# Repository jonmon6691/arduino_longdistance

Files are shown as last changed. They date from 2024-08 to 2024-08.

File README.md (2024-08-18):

# arduino_LongDistance
An improvement to [arduino_RustysCalling](https://github.com/jonmon6691/arduino_rustyscalling/) that increases range, responsiveness, battery life, reduces complexity, and even folds your laundry!

## Todo
* Clean up phone wiring, can I get a new handset??
* Add wiring for dial
* Power button
  * Toggle button with LED
  * LED can be powered directly with 3.3V output, brightness is good at 2k series R, current is only .5ma

## Remote
This module is simply a button and a LoRa transmitter.

While the button is pressed, the remote transmitts packets as fast as it can. Otherwise it's idle, not sending anything.

Note: To maximize the packet rate (and therefore increase the responsiveness), the modems use the `.setModemConfig(RH_RF95::Bw500Cr45Sf128)` setting to optimize speed at the cost of distance. In practice this results in a packet every 8ms. The range appears to be more than sufficient, even when the rx is closed inside the phone.

### Feather Option
https://www.adafruit.com/product/3178

Battery life for a SAMD Radiofruit with a 350mAh little lipo pack is about 1 week. Would be nice if this was replaceable...
<br />
__Note:__ that's with 1mA while asleep (not using RFM sleep), 120mA while transmitting

### BSN3 Option
https://github.com/EasySensors/ButtonSizeNode3

Programs just like an Arduino Pro Mini, directly with an FTDI cable. Using sleep state for the Mega and for radio its down to 4 microamps. The two CR2032's (255mAh @ 6.5V) should last 7 years!!! I need to double check my ammeter tbh

## Phone
The LoRa receiver also orchestrates the phones other functions

### Ringer
Every time the phone receives a LoRa packet, it will run the ringer for the next 20 milliseconds. Since the packets come every 8ms, this means the ringer will stay on without interruption while the remote button held down, and will ring for about 20ms after its released. Which isn't noticeable.

To turn on the ringer, the microcontroller drives the gate of an N-channel FET with a 3.3k pulldown resistor. That FET provides a path to ground for a ringer module which converts the DC of a 9V battery into 70V 20Hz AC to power the ringer directly.

* Experiments on making the ringer louder
  * 2x A23 in parallel,(172mA) Not significantly louder, but less voltage drop during ringing (4v drop vs 2v drop) and will probably last a lot longer
  * 12v wall wart, (210mA) not significantly louder, no voltage drop at all while ringing.
  * 1x 9V, (160mA) not significantly quieter, but could in theory last a lot longer, like 20x
  * 2x A23 in series (24v) doesn't work, but thankfully, doesn't break the ringer either
  * 2x 9V in series (18.5v) doesn't work, but thankfully, doesn't break the ringer either
  * __Conclusion__: Using single 9V battery for convinience and longevity
* Power consumption
  * ESP + Lora listening = 81mA! 68mA of that is from the ESP by itself. Surely there's a way to lower this, maybe Wifi or BT is on??
  * Audio FX board: 29mA idle

### Playing audio
When the handset is lifted off the cradle, the phone will play a random audio file through the speaker.

The audio is generated by an Adafruit SFX board which is controlled using UART from the LoRa receiver module.

When the handset is placed back on the cradle, the audio will stop.

When the dial is turned and the handset is off the cradle, the current audio will be interrupted and the phone will play a giggling noise. When it's released, it will start a new audio.

The ground of the audio board is driven with another FET like the ringer module so that the power consumption can be cut by the main controller.

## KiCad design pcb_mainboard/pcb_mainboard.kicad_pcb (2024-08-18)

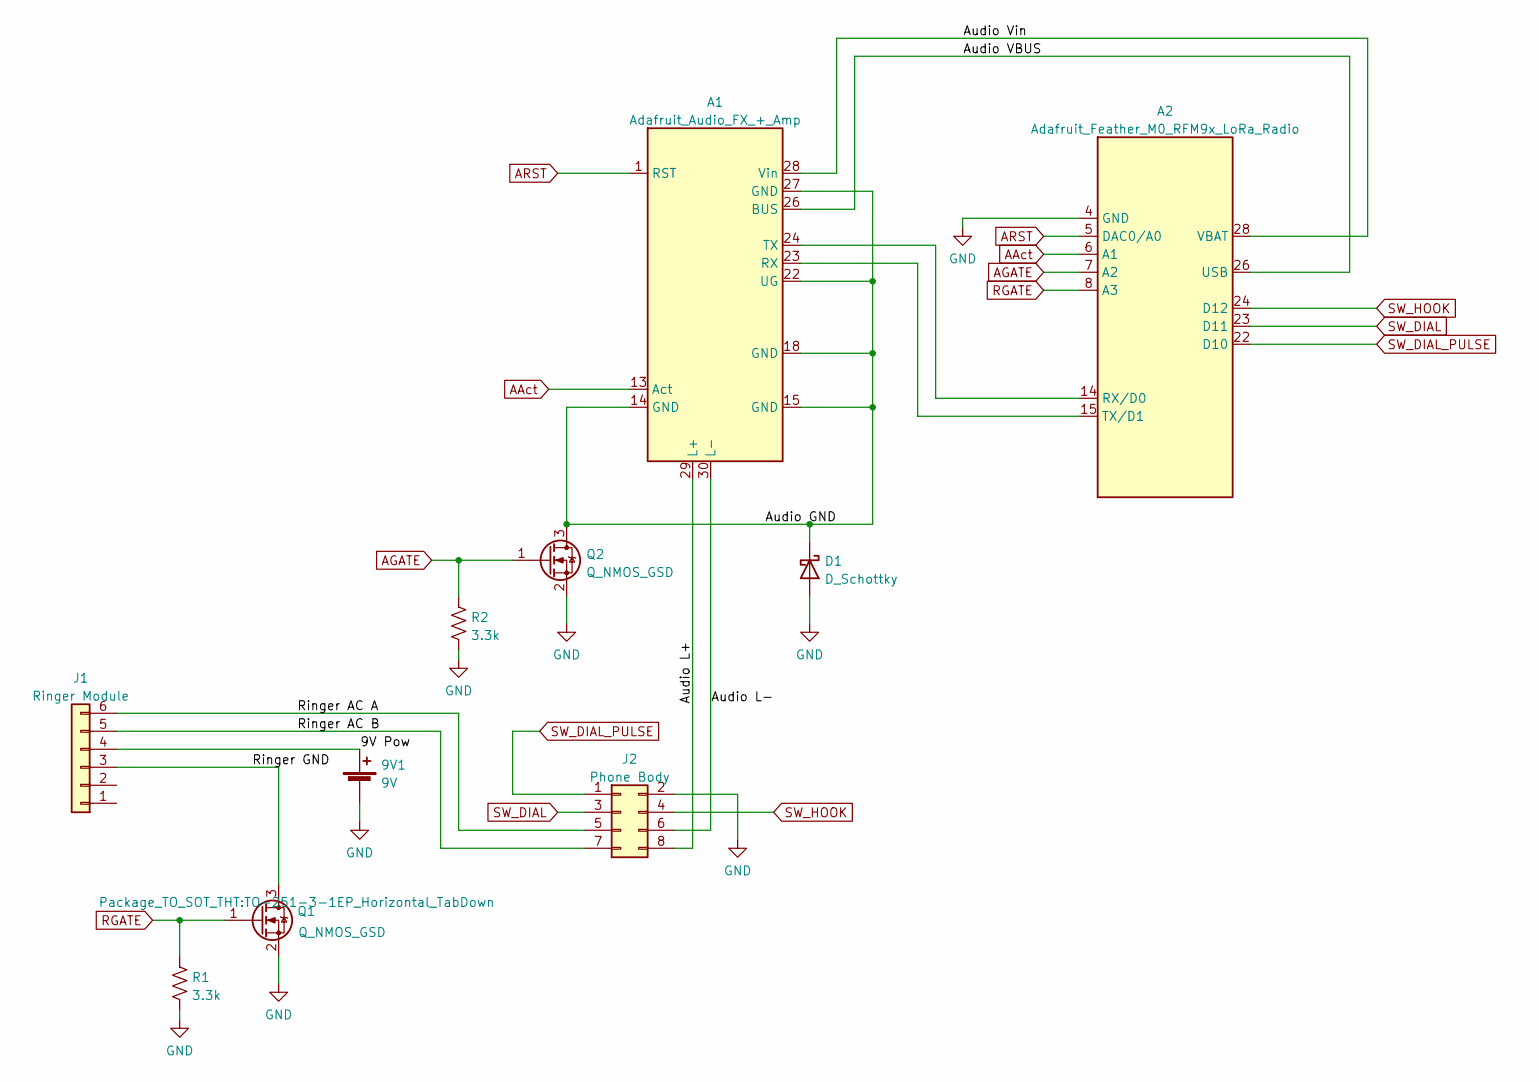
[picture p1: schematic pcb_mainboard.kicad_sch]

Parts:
9V1: 9V; PinHeader_1x02_P2.54mm_Vertical
A1: Adafruit_Audio_FX_+_Amp; Adafruit Audio FX + Amp
A2: Adafruit_Feather_M0_RFM9x_LoRa_Radio; Adafruit_Feather_M0_RFM
D1: D_Schottky; D_DO-41_SOD81_P7.62mm_Horizontal
J1: Ringer Module; PinHeader_1x06_P2.54mm_Vertical
J2: Phone Body; PinSocket_2x04_P2.54mm_Vertical
Q1, Q2: Q_NMOS_GSD; TO-251-3-1EP_Horizontal_TabDown
R1, R2: 3.3k; R_Axial_DIN0204_L3.6mm_D1.6mm_P5.08mm_Horizontal

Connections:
/9V Pow: 9V1.1 (+), J1.4
/Audio GND: A1.14 (GND), A1.15 (GND), A1.18 (GND), A1.22 (UG), A1.27 (GND), D1.1 (K), Q2.3 (D)
/Audio L+: A1.29 (L+), J2.8
/Audio L-: A1.30 (L-), J2.6
/Audio VBUS: A1.26 (BUS), A2.26 (USB)
/Audio Vin: A1.28 (Vin), A2.28 (VBAT)
/Ringer AC A: J1.6, J2.5
/Ringer AC B: J1.5, J2.7
/Ringer GND: J1.3, Q1.3 (D)
AAct: A1.13 (Act), A2.6 (A1)
AGATE: A2.7 (A2), Q2.1 (G), R2.1
ARST: A1.1 (RST), A2.5 (DAC0/A0)
GND: 9V1.2 (-), A2.4 (GND), D1.2 (A), J2.2, Q1.2 (S), Q2.2 (S), R1.2, R2.2
unnamed: A1.23 (RX), A2.15 (TX/D1)
unnamed: A1.24 (TX), A2.14 (RX/D0)
RGATE: A2.8 (A3), Q1.1 (G), R1.1
SW_DIAL: A2.23 (D11), J2.3
SW_DIAL_PULSE: A2.22 (D10), J2.1
SW_HOOK: A2.24 (D12), J2.4

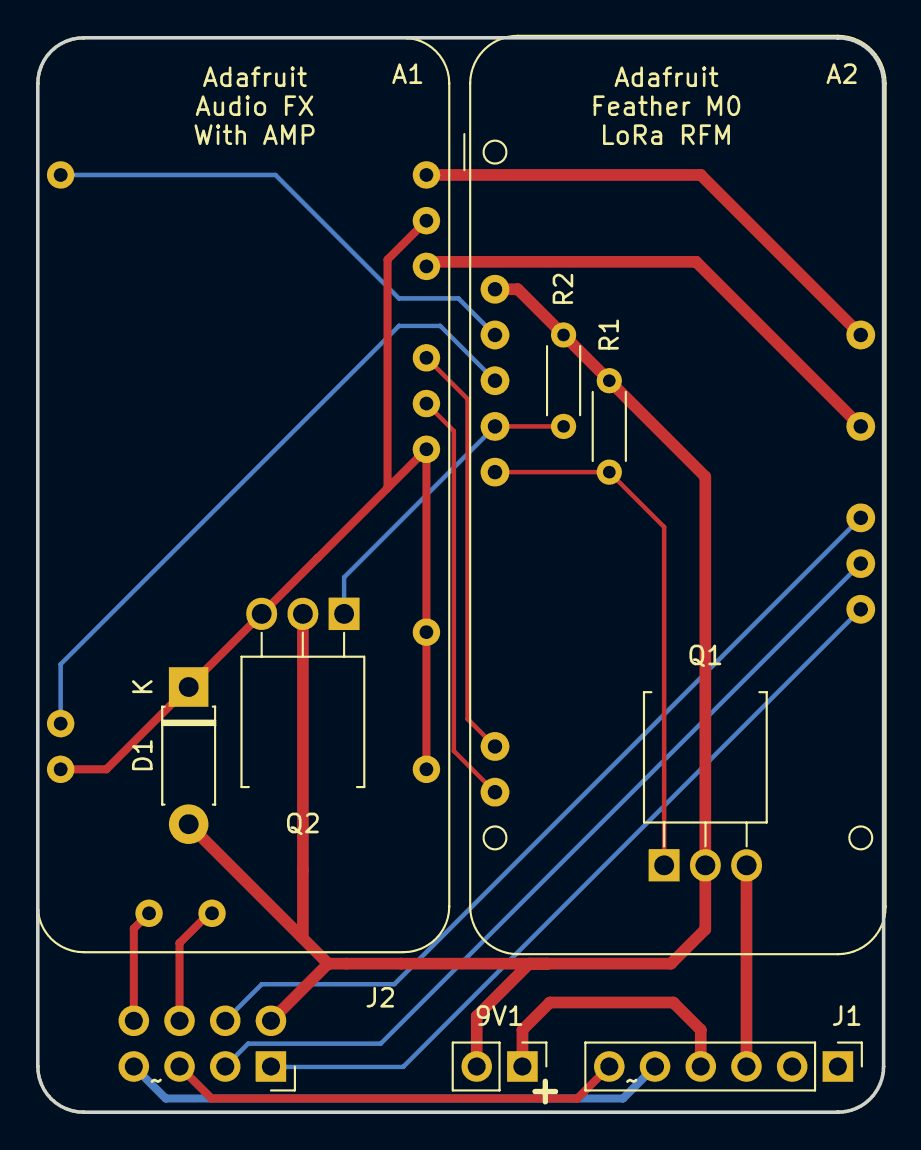
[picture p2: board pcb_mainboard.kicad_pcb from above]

Board: 2 copper layers, 47.0 x 59.7 mm, 10 parts (0 on the bottom side), 19 nets.

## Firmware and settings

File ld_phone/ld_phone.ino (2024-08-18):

// rf95_server.pde
// -*- mode: C++ -*-

#include <SPI.h>
#include <RH_RF95.h>
#include <Adafruit_Soundboard.h>

#define RINGER_PWR 26
#define AFX_PWR 25
#define AFX_ACT 32
#define AFX_RST 12
#define SW_OFF_HOOK 14
#define SW_DIAL 22

// ESP32 feather w/wing (Jon's dumb wiring)
#define RFM95_CS 33   // "B"
#define RFM95_INT 15  // "C"
#define RFM95_RST 27  // "A"

// Not used since they are implicit in the Arduino-provided "Serial1" object
#define AFX_TX 16
#define AFX_RX 17

#define MAX_AFX_RETRIES 1
#define AFX_STATE_OFF 0
#define AFX_STATE_INIT 1
#define AFX_STATE_UP 2
#define AFX_STATE_MISSING 3
uint8_t afx_state;

RH_RF95 rf95(RFM95_CS, RFM95_INT);
Adafruit_Soundboard afx = Adafruit_Soundboard(&Serial1, NULL, AFX_RST);

#define ACTIVATION_MS 20  // Minimum on-time possible (theoretically 8ms, 10ms didn't work, 20 is plenty responsive and seems to work fine)
unsigned long t_ring_until;
unsigned long t_awake_until;

// Stores the number of files, and incidentally, the length of *playlist
uint8_t num_files;

// Stores the order to play the song's in, by index
uint8_t *playlist;

// Stores the track to be played
uint8_t track_i;

void init_phone() {
  digitalWrite(RINGER_PWR, LOW); pinMode(RINGER_PWR, OUTPUT);
  pinMode(SW_OFF_HOOK, INPUT_PULLUP);
  pinMode(SW_DIAL, INPUT_PULLUP);
  t_ring_until = 0;
}

void init_LoRa() {
  pinMode(RFM95_RST, OUTPUT);
  digitalWrite(RFM95_RST, HIGH);

  // Defaults after init are 434.0MHz, 13dBm, Bw = 125 kHz, Cr = 4/5, Sf = 128chips/symbol, CRC on
  if (!rf95.init()) Serial.println("init failed");
  if (!rf95.setFrequency(915.0)) Serial.println("setFrequency failed");
  if (!rf95.setModemConfig(RH_RF95::Bw500Cr45Sf128)) Serial.println("setModemConfig failed");

  // The default transmitter power is 13dBm, using PA_BOOST.
  rf95.setTxPower(20, false);
}

void init_audio() {
  afx_state = AFX_STATE_OFF;
  pinMode(AFX_PWR, OUTPUT); digitalWrite(AFX_PWR, HIGH);
  afx_state = AFX_STATE_INIT;
  pinMode(AFX_ACT, INPUT_PULLUP);

  // Sound board talks on Serial1
  Serial1.begin(9600);
  for (uint8_t i = 0; i < MAX_AFX_RETRIES; i++) {
    if (afx.reset()) {
      afx_state = AFX_STATE_UP;
      break;
    } else {
      afx_state = AFX_STATE_MISSING;
    }
  }

  num_files = afx.listFiles();
  playlist = (uint8_t *) malloc(sizeof(uint8_t) * num_files);
  track_i = 0;

  // Initialize playlist
  for (int i = 0; i < num_files; i++) playlist[i] = i;
  shuffle_playlist();
}

void setup() {
  pinMode(LED_BUILTIN, OUTPUT); digitalWrite(LED_BUILTIN, HIGH);
  Serial.begin(9600);
  Serial.println("Server up");

  init_phone();
  init_LoRa();
  init_audio();

  t_awake_until = millis() + 2000;

  Serial.println("Setup finished.");
  digitalWrite(LED_BUILTIN, LOW);
}

void shuffle_playlist() {
  // Fisher-yates and Durstenfeld with the good shuffle
  // for i from n−1 down to 1 do
  for (int i = num_files - 1; i > 0; i--) {
    // j gets random integer such that 0 <= j <= i
    int j = random(i+1); 
    // exchange [j] and [i]
    uint8_t tmp = playlist[i];
    playlist[i] = playlist[j];
    playlist[j] = tmp;
  }
}

// returns the new state
uint8_t handle_audio(uint8_t in_state) {
  uint8_t power = digitalRead(AFX_PWR) == HIGH;
  switch (in_state) {
  case AFX_STATE_OFF:
    if (power) return AFX_STATE_INIT;
    break;

  default:
  case AFX_STATE_INIT:
    if (!power) return AFX_STATE_OFF;
    if (!afx.reset()) return AFX_STATE_INIT;
    return AFX_STATE_UP;
    break;

  case AFX_STATE_UP:
    if (!power) return AFX_STATE_OFF;
    return AFX_STATE_UP;
    break;

  case AFX_STATE_MISSING:
    return AFX_STATE_MISSING;
    break;
  }
}

void loop() {
  if (rf95.available()) {
    // Should be a message for us now
    uint8_t buf[RH_RF95_MAX_MESSAGE_LEN];
    uint8_t len = sizeof(buf);
    if (rf95.recv(buf, &len)) {
      t_ring_until = millis() + ACTIVATION_MS;
      t_awake_until = millis() + 2000;
    }
  }

  // Ring the bell
  if (millis() < t_ring_until) {
    digitalWrite(RINGER_PWR, HIGH);
    digitalWrite(LED_BUILTIN, HIGH);
  } else {
    digitalWrite(RINGER_PWR, LOW);
    digitalWrite(LED_BUILTIN, LOW);
  }

  // Power up the audio module while the ringer is off the hook
  if (digitalRead(SW_OFF_HOOK) == LOW) {
    digitalWrite(AFX_PWR, HIGH);
  } else {
    digitalWrite(AFX_PWR, LOW);
  }

  // Audio module state machine
  afx_state = handle_audio(afx_state);

  // If the ringer module is up and running, not playing already, and there's files on the board
  if (afx_state == AFX_STATE_UP && digitalRead(AFX_ACT) == HIGH && num_files > 0) {
    // Play one from the shuffled list
    afx.playTrack(playlist[track_i++]);
    // Reshuffle the playlist once we get to the end
    if (track_i >= num_files) {
      track_i = 0;
      shuffle_playlist();
    }
  }

  // Go to sleep
  if (millis() > t_awake_until) {
    esp_sleep_enable_ext0_wakeup(gpio_num_t::GPIO_NUM_15, 1);
    esp_light_sleep_start();
  }
}

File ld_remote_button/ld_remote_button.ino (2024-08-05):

#include <LowPower.h>
#include <RH_RF95.h>

// ButtonSizedNodeV3
#define BUTTON_PIN     3
#define BUTTON_GND_PIN     5
#define LED_PIN     6
#define RFM95_CS    10
#define RFM95_INT   2
#define RFM95_RST   16


RH_RF95 rf95(RFM95_CS, RFM95_INT);

void init_LoRa() {
  pinMode(RFM95_RST, OUTPUT);
  digitalWrite(RFM95_RST, HIGH);
  
  // Set up radio:
  // Defaults after init are 434.0MHz, 13dBm, Bw = 125 kHz, Cr = 4/5, Sf = 128chips/symbol, CRC on
  if (!rf95.init()) Serial.println("init failed");
  if (!rf95.setFrequency(915.0)) Serial.println("setFrequency failed");
  if (!rf95.setModemConfig(RH_RF95::Bw500Cr45Sf128)) Serial.println("setModemConfig failed");
  // The default transmitter power is 13dBm, using PA_BOOST.
  rf95.setTxPower(20, false);

}

unsigned long t_sleep_stamp; // Holds the millis() timestamp after which the remote should sleep
#define SLEEP_TIME_MS 1000 // Sleep after the last time the button was down

void wakeup_handler() {}
void button_sleep() {
  attachInterrupt(digitalPinToInterrupt(BUTTON_PIN), wakeup_handler, CHANGE);
  
  //rf95.setModeIdle();
  rf95.sleep();

  // Enter power down state with ADC and BOD module disabled.
  // Wake up when wake up pin is low.
  LowPower.powerDown(SLEEP_FOREVER, ADC_OFF, BOD_OFF); 
  // Disable external pin interrupt on wake up pin.
  detachInterrupt(digitalPinToInterrupt(BUTTON_PIN)); 
  
  rf95.setModeTx();
}

void setup() {
  pinMode(BUTTON_PIN, INPUT_PULLUP);

  digitalWrite(BUTTON_GND_PIN, LOW);
  pinMode(BUTTON_GND_PIN, OUTPUT);

  digitalWrite(LED_PIN, LOW);
  pinMode(LED_PIN, OUTPUT);

  init_LoRa();

  t_sleep_stamp = millis() + SLEEP_TIME_MS;
}

void loop() {
  uint8_t data[] = "";
  if (!digitalRead(BUTTON_PIN)) {
  // if (millis() / 500 % 2) {
    rf95.send(data, 0);
    rf95.waitPacketSent();
    digitalWrite(LED_PIN, HIGH);
    t_sleep_stamp = millis() + SLEEP_TIME_MS;
  } else {
    digitalWrite(LED_PIN, LOW);
  }

  if (millis() > t_sleep_stamp) {
    button_sleep();
    // Waiting for interrupt
    t_sleep_stamp = millis() + SLEEP_TIME_MS;
  }
}

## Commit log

2024-07-27 Fix import low power lab was the wrong choice.
    [ld_remote.ino]
2024-08-04 PCB v1
    [pcb_mainboard.kicad_pcb, pcb_mainboard.kicad_sch]
2024-08-18 sound board state machine
2024-08-18 news flash bucko
2024-08-18 V1 board as sent to oshpark
    [pcb_mainboard.kicad_pcb, pcb_mainboard.kicad_sch]
